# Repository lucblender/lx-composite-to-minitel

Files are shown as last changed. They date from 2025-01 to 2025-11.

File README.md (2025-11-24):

# lx-composite-to-minitel

KiCad project of a Minitel mod to add composite video input.
Projet KiCad d'une modification de Minitel pour ajouter une entrée vidéo composite.

## Pictures

top
bottom

## En

### Description

*Français en dessous*

The goal of this project is to be able to enter a French Minitel with composite video. This project takes back the work from cfp-radio that you can find on their [website]( https://www.cfp-radio.com/realisations/rea48/minitel-01.html).
The cfp-radio project goal was to give audio and video to a Minitel. In my case, I only took the video part. I took back their schematic and made my own PCB all in SMD. All PCB shown in pictures in this repo are manufactured using [PCBWay](https://pcbway.com) services.

PCBWay provides high-quality PCB manufacturing with reliable service and fast turnaround times, making them my first choice for prototyping as seen in this Minitel project. They can also make more complex PCB to fit any of your requirements.

### KiCad project

The KiCad project can be found under the [av-to-minitel](/av-to-minitel/). The BOM has [mouser](https://www.mouser.ch) reference for all each component.

For the PCB, I created a rounded track version to fit a bit the look of the Minitel PCB with the help of the [kicad-round-tracks](https://github.com/mitxela/kicad-round-tracks) plugin. This PCB is the main PCB [av-to-minitel.kicad_pcb](/av-to-minitel/av-to-minitel.kicad_pcb). The original PCB with normal "square" tracks can be found under the [av-to-minitel-angled.kicad_pcb](/av-to-minitel/av-to-minitel-angled.kicad_pcb) file.

### Assembly

The output connector of the PCB is too small to fit the Minitel board (2.54mm pitch versus 5.08mm pitch). In my case, I unsoldered the original Minitel 5.08 pin header and made a custom adapter cable to fit the Minitel board. See the below picture for more detail.

## Fr

### Description

Le but de ce projet est d'ajouter une entrée composite vidéo à un minitel français. Ce projet reprend le travail de cfp-radio qui peut être retrouvé sur leur site [internet]( https://www.cfp-radio.com/realisations/rea48/minitel-01.html).

Le but du projet de cfp-radio est de rajouter de l'audio et de la vidéo à un minitel. Dans mon cas, je n'ai réalisé que la partie vidéo. J'ai repris leur schématique et réalisé mon propre PCB en smd. Tous les PCBs montrés dans ce repo ont été fabriqués à l'aide des services de [PCBWay](https://pcbway.com).

PCBWay propose une fabrication de PCB de haute qualité avec un service fiable et des délais d'exécution rapides, ce qui en fait mon premier choix pour le prototypage comme le montre ce projet lié au Minitel. Ils peuvent également fabriquer des PCBs plus complexes pour répondre à toutes vos exigences.

### Projet KiCad

Le projet KiCad se trouve dans le dossier [av-to-minitel](/av-to-minitel/). La BOM contient des références [mouser](https://www.mouser.ch) pour chaque composant.

Pour le PCB, j'ai utilisé des pistes arrondies pour avoir un style similaire au vieux PCB du Minitel avec l'aide du plugin [kicad-round-tracks](https://github.com/mitxela/kicad-round-tracks). Ce PCB est le PCB principal [av-to-minitel.kicad_pcb](/av-to-minitel/av-to-minitel.kicad_pcb). La version originale avec des pistes "coudées" se trouve dans le fichier [av-to-minitel-angled.kicad_pcb](/av-to-minitel/av-to-minitel-angled.kicad_pcb).

### Assemblage

Le connecteur de sortie du PCB est trop petit pour s'adapter à la carte Minitel (espacement de 2,54 mm contre 5,08 mm). Dans mon cas, j'ai dessoudé le pin header d'origine du Minitel de 5,08mm de pitch et fabriqué un câble adaptateur custom pour s'adapter à la carte Minitel. Voir l'image ci-dessous pour plus de détails.

## Assembly - Assemblage

### Adapter cable - Cable d'adaptation

As said earlier, I took back the 5.08 pitch pin header from the minitel "display card" and soldered some wires + 2.54mm pitch connector to make an easy adapter to the board.

adapter cable

### Mouted - Monté

Without the main Minitel "display card" there is enough room to let the new composite adapter card "float" in that new free space.

top mounted
bottom mounted

## Schematic

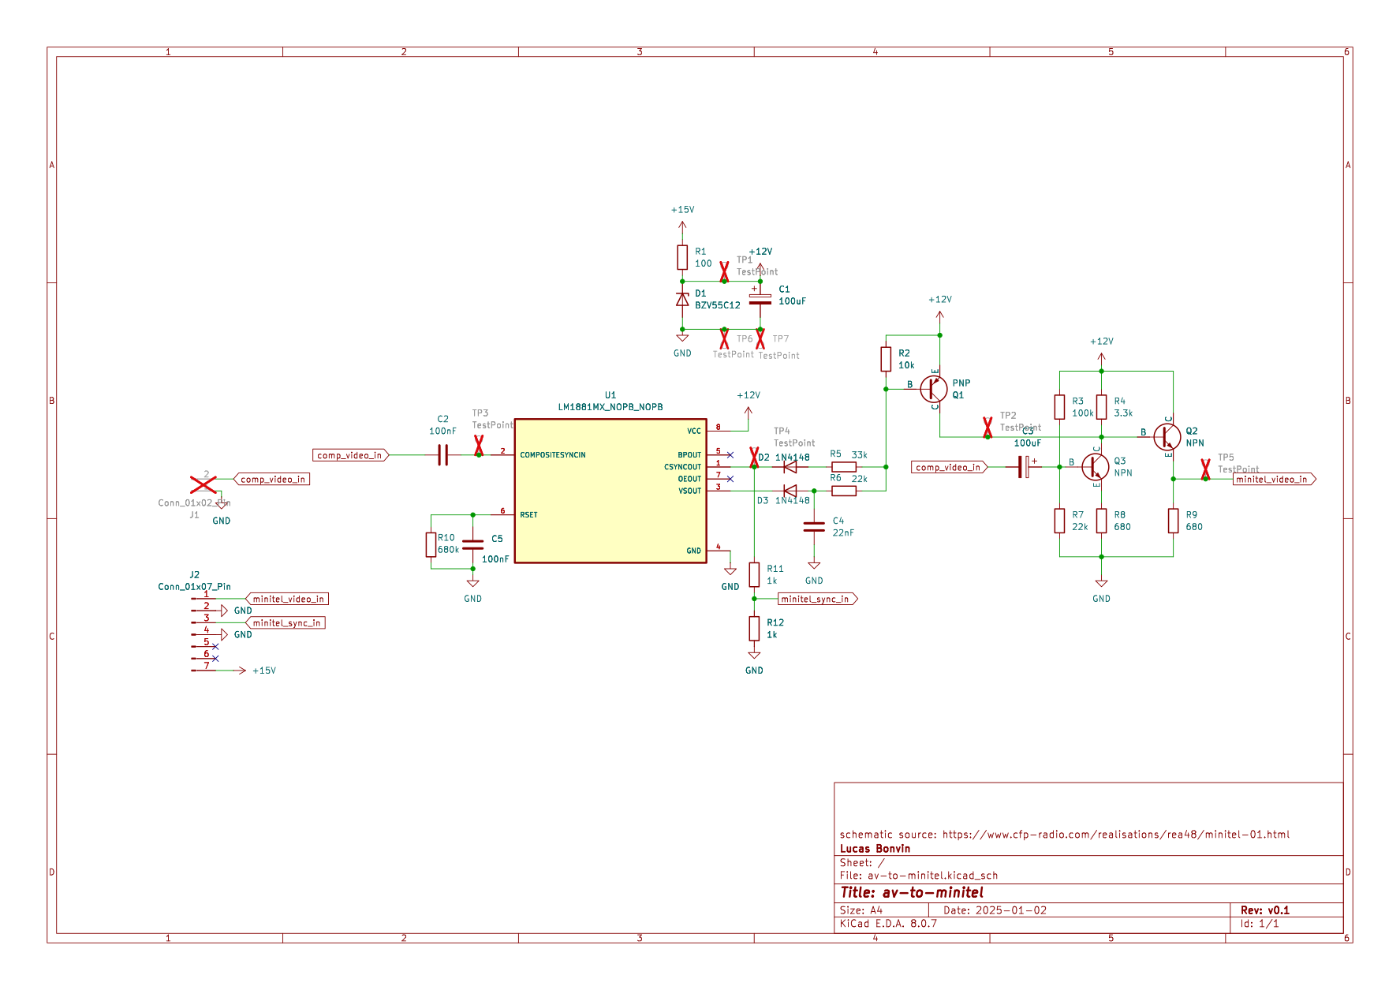
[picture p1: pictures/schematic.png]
schematic


## License

This project is under [CC BY-SA 4.0](https://creativecommons.org/licenses/by-sa/4.0/) license.

You are free to:

- Share — copy and redistribute the material in any medium or format for any purpose, even commercially.
- Adapt — remix, transform, and build upon the material for any purpose, even commercially.
The licensor cannot revoke these freedoms as long as you follow the license terms.

## Video Demo

Demo with a raspberry pi running [Auto Waaave](https://andreijaycreativecoding.com/AUTO-WAAAVE-MANUAL) by Andrei_Jay.

<https://github.com/user-attachments/assets/5a00ba67-d3fa-4769-bc9c-a68b00cb2784>

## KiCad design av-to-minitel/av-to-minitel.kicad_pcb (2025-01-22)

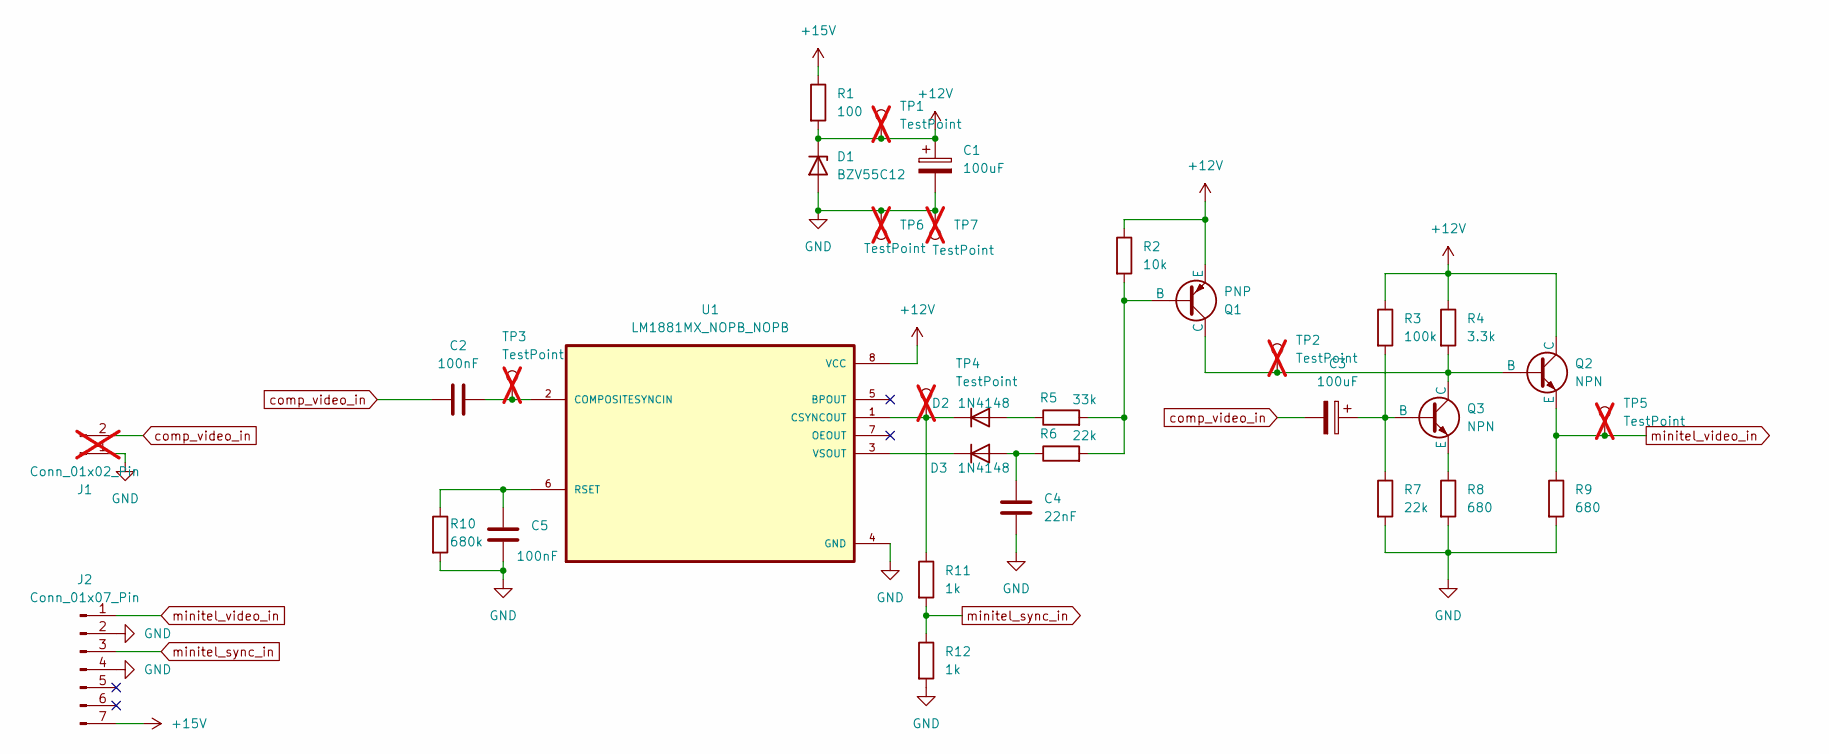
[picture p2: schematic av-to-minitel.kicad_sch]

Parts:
C1, C3: 100uF; CP_Elec_5x5.8; Mouser reference 667-EEE-FN1C101UR
C2, C5: 100nF; C_0603_1608Metric; Mouser reference 710-885012206071R
C4: 22nF; C_0603_1608Metric; Mouser reference C0603C223K3RACTM
D1: BZV55C12; D_MiniMELF; Mouser reference 771-BZV55-C12-T/R
D2, D3: 1N4148; D_SOD-323F; Mouser reference 637-1N4148WS-AQ
J1: Conn_01x02_Pin; PinHeader_1x02_P2.54mm_Horizontal; not fitted
J2: Conn_01x07_Pin; PinHeader_1x07_P2.54mm_Horizontal; Mouser reference 649-1012937990701BLF
Q1: PNP; SOT-23; Mouser reference 241-MMBT2907AR100001
Q2, Q3: NPN; SOT-23; Mouser reference 522-FMMT619TA
R1: 100; R_0805_2012Metric; Mouser reference RT0805FRE07100RL
R2: 10k; R_0805_2012Metric; Mouser reference CRCW080510K0JNEC
R3: 100k; R_0805_2012Metric; Mouser reference CRGCQ0805J100K
R4: 3.3k; R_0805_2012Metric; Mouser reference CRCW08053K30JNEA
R5: 33k; R_0805_2012Metric; Mouser reference RC0805JR-1333KL
R6, R7: 22k; R_0805_2012Metric; Mouser reference CR0805-FX-2202ELF
R8, R9: 680; R_0805_2012Metric; Mouser reference CRCW0805680RJNEBC
R10: 680k; R_0805_2012Metric; Mouser reference CR0805-FX-6803ELF
R11, R12: 1k; R_0805_2012Metric; Mouser reference RCA08051K00FKEA
TP1, TP2, TP3, TP4, TP5, TP6, TP7: TestPoint; TestPoint_THTPad_D1.0mm_Drill0.5mm; not fitted
U1: LM1881MX_NOPB_NOPB; SOIC127P599X175-8N; Mouser reference 926-LM1881MX/NOPB

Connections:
+12V: C1.1, D1.1 (K), Q1.3 (E), Q2.1 (C), R1.2, R2.1, R3.1, R4.1, TP1.1, U1.8 (VCC)
+15V: J2.7, R1.1
GND: C1.2, C4.1, C5.1, D1.2 (A), J1.1, J2.2, J2.4, R7.2, R8.2, R9.2, R10.2, R12.2, TP6.1, TP7.1, U1.4 (GND)
unnamed: D2.2 (A), R5.1
unnamed: D2.1 (K), R11.1, TP4.1, U1.1 (CSYNCOUT)
unnamed: C4.2, D3.2 (A), R6.1
unnamed: D3.1 (K), U1.3 (VSOUT)
unnamed: Q1.2 (B), R2.2, R5.2, R6.2
unnamed: Q1.1 (C), Q2.2 (B), Q3.1 (C), R4.2, TP2.1
unnamed: C3.1, Q3.2 (B), R3.2, R7.1
unnamed: Q3.3 (E), R8.1
unnamed: C2.2, TP3.1, U1.2 (COMPOSITESYNCIN)
unnamed: C5.2, R10.1, U1.6 (RSET)
comp_video_in: C2.1, C3.2, J1.2
minitel_sync_in: J2.3, R11.2, R12.1
minitel_video_in: J2.1, Q2.3 (E), R9.1, TP5.1

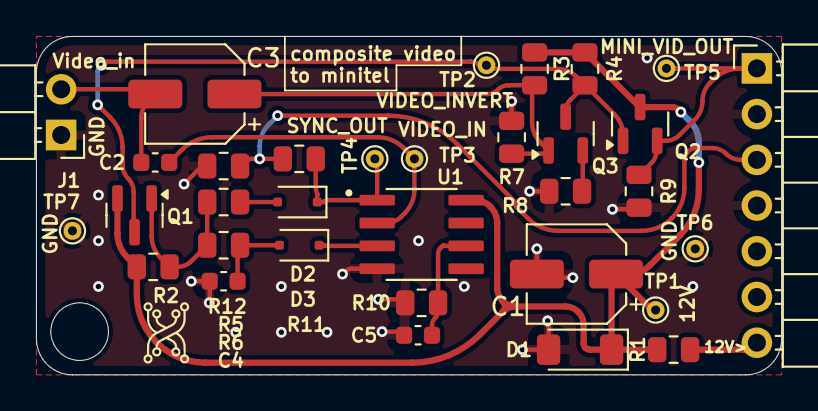
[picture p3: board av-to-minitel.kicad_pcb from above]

Board: 2 copper layers, 41.4 x 18.8 mm, 33 parts (0 on the bottom side), 16 nets.

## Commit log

2025-01-22 feature: commit source files
    [av-to-minitel-B_Cu.gbr, av-to-minitel-B_Mask.gbr, av-to-minitel-B_Paste.gbr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]
2025-01-22 feature: add pcbway reference and address the connector pitch error
2025-01-28 fix: fix schematic placement
    [av-to-minitel.kicad_sch]
2025-01-28 feature: add assembly pictures
2025-02-05 fix: fix readme and put a png of schematic to have white background
